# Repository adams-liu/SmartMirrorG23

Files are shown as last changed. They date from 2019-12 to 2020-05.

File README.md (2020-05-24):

# Smart Mirror Capstone Project :desktop_computer:

This project uses an amazon echo to communicate with the Raspberry Pi to create a hands-free media experience for the user.  We used [MagicMirror](https://github.com/MichMich/MagicMirror) repository as a reference for our work, they have a community to help you get started with your own magic mirror project. Click [here](Reports/G36-490_Final_Report.pdf) to see the full final report.
## Bill of Materials :dollar:
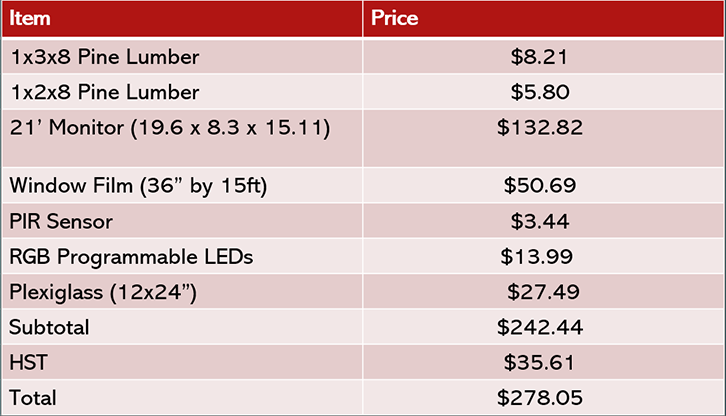
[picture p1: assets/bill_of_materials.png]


## Hardware Design :computer:
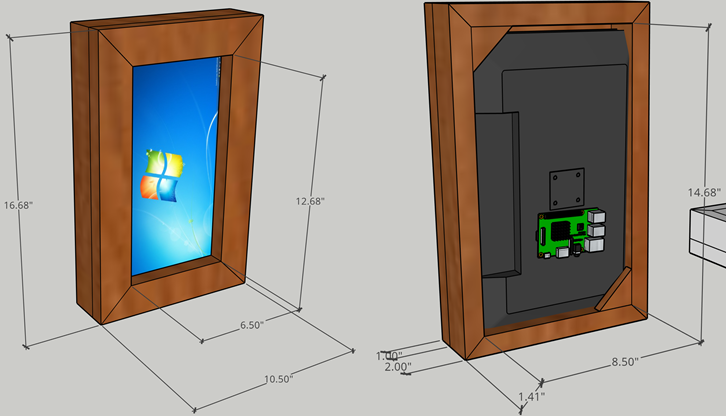
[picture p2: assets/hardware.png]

## Alexa Voice Integration :microphone:
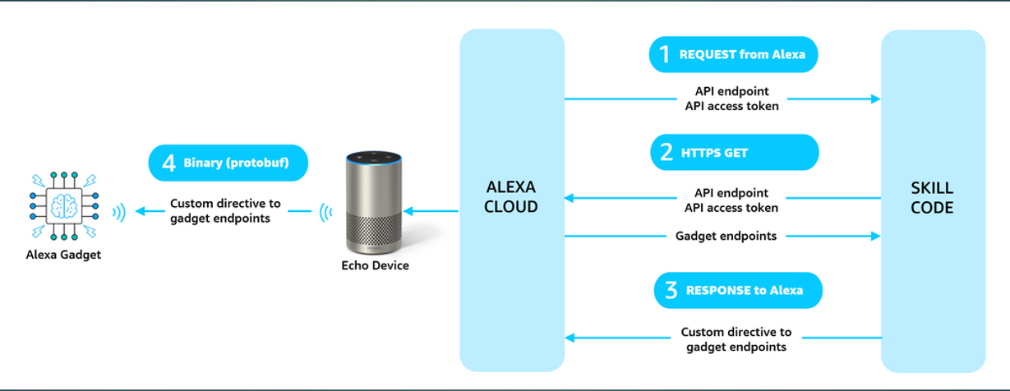
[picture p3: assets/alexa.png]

## User Interface :eyes:
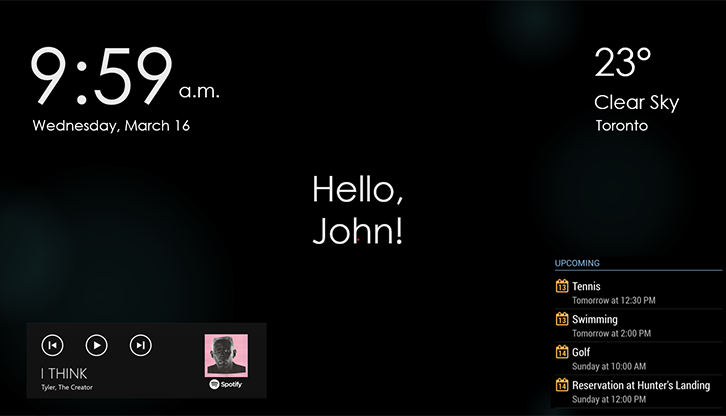
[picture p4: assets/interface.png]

## Starting the Mirror :running_man:
 > *This section is currently still being finished*

## Team :necktie:
- **Adams Liu** : Alexa Voice Integration
- **Ian Chang**: Hardware and Frame
- **Kingsley Chu**: User Interface

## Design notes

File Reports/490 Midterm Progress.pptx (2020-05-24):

## Smart Mirror

Midterm Progress
Group 36: Kingsley Chu, Adams Liu, Ian Chang
Date: dEC/05/2019

## Divided the roles into 3 parts

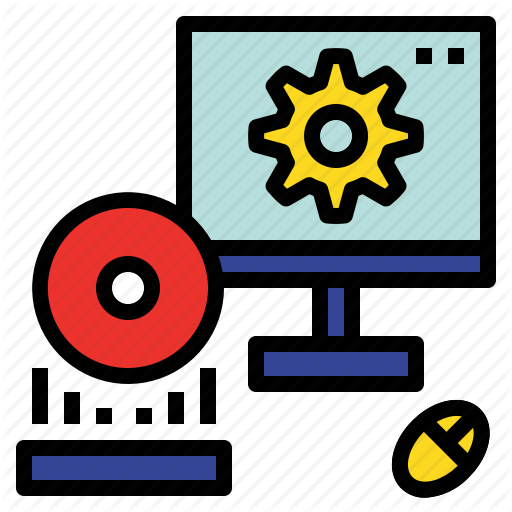
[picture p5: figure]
A close up of a logo Description generated with very high confidence

Hardware/Frame Development
[Ian Chang]

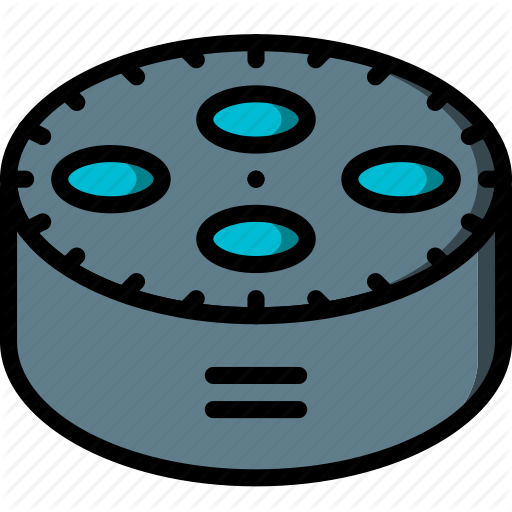
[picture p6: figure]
A close up of a device Description generated with high confidence

Amazon Voice Development
[Adams Liu]

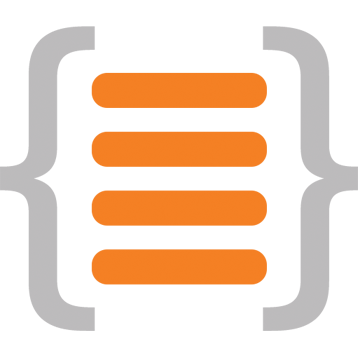
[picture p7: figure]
A picture containing flower Description generated with very high confidence

Fullstack + GUI Development
[Kingsley Chu]

## Hardware & Materials

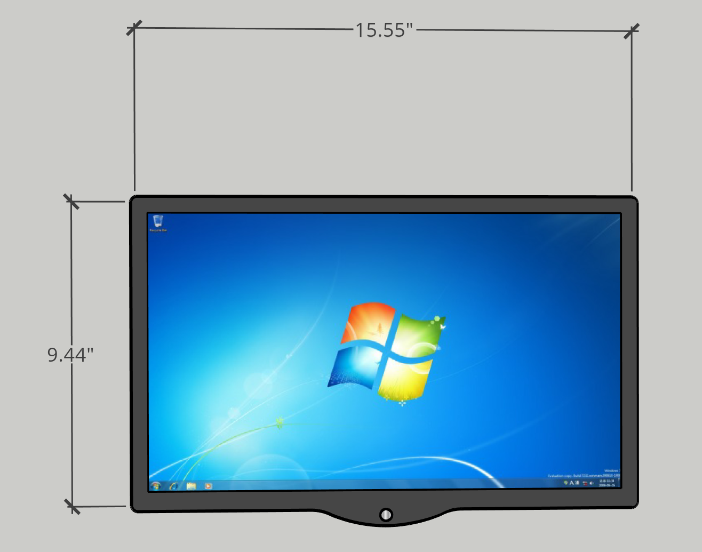
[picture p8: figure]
A flat screen tv sitting on top of a computer Description generated with very high confidence
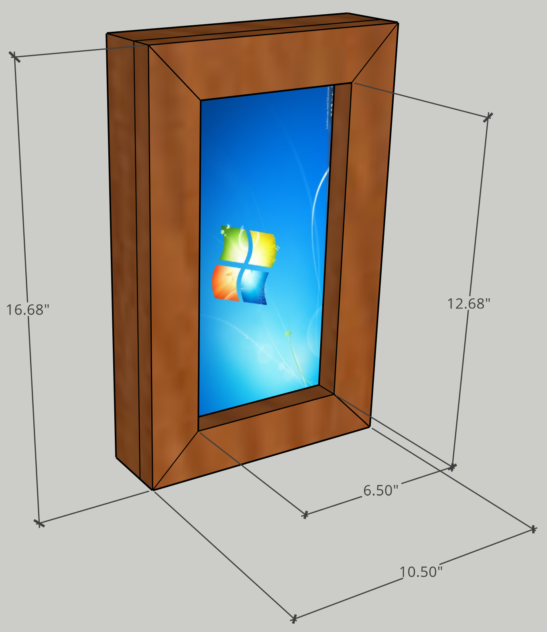
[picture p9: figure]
A picture containing computer Description generated with very high confidence
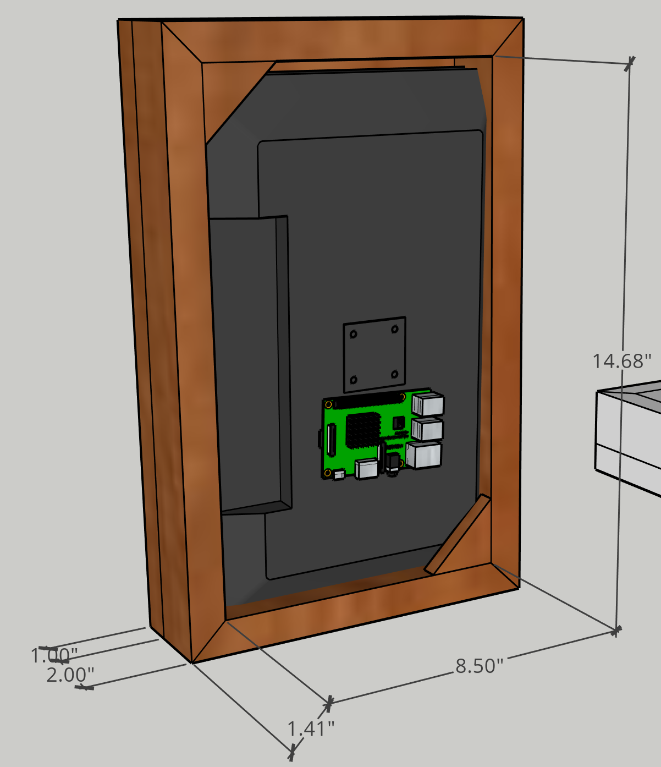
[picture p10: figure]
A picture containing table Description generated with very high confidence

## List of Materials

Item | Price
1x3x8 Pine Lumber | $8.21
1x2x8 Pine Lumber | $5.80
21’ Monitor (19.6 x 8.3 x 15.11) | $132.82
Window Film (36” by 15ft) | $50.69
PIR Sensor | $3.44
RGB Programmable LEDs | $13.99
Plexiglass (12x24”) | $27.49
Subtotal | $242.44
HST | $35.61
Total | $278.05

## Alexa voice integration

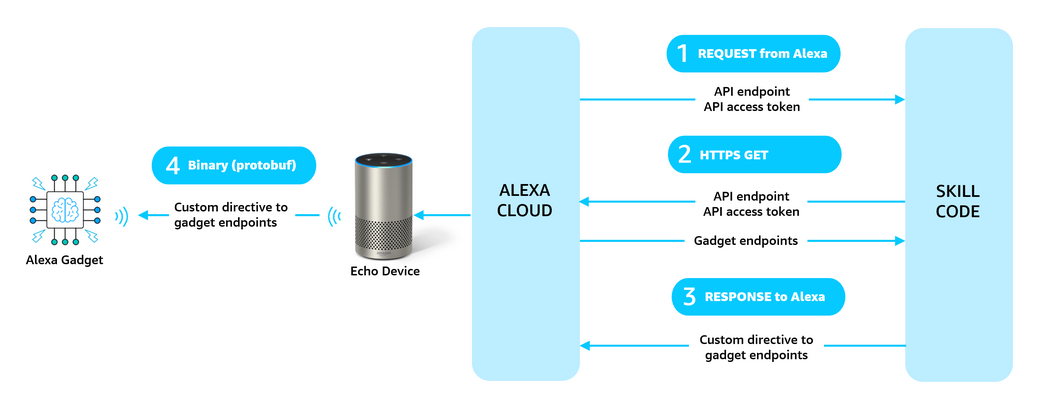
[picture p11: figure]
A screenshot of a cell phone Description generated with very high confidence

## Voice User Interface

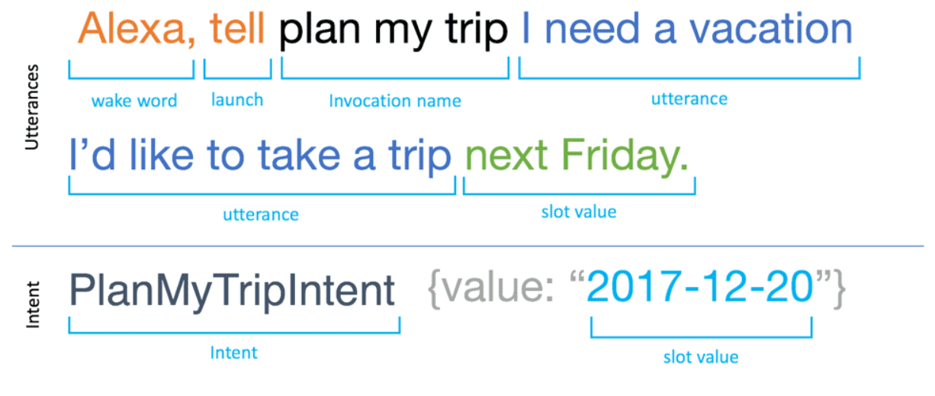
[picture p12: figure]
A screenshot of a cell phone Description generated with very high confidence

## Utterance and Intent (Schedule)

- Utterance:
  - "what's my schedule"?
  - "what does my schedule look like for today?"
  - "what's today's agenda?"
  - "what's today's to-do list?"
  - "what am I doing today?"

Intent 1: ReadScheduleIntent {value: 2019-12-05}
Call onto calendar API and return and responds by listing out schedule items for listed date

Intent 2: OpenCalendarIntent {value: 2019-12-05}
Communicates with Raspberry Pi to launch Calendar display for listed date

## Software & UI

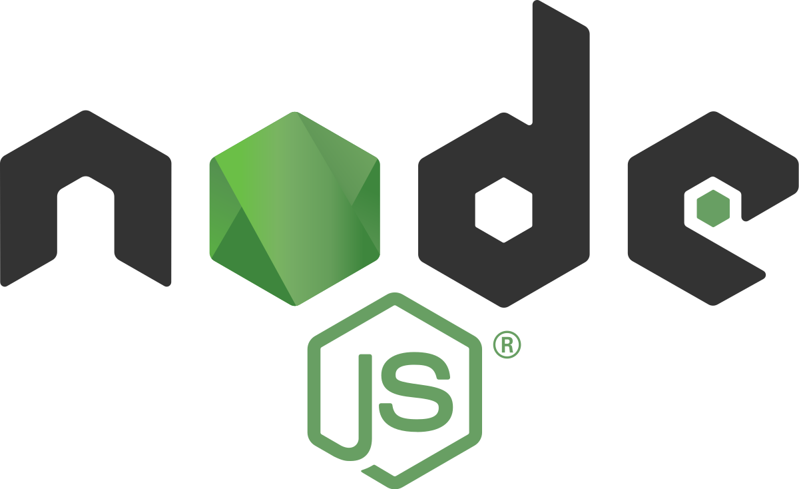
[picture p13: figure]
A close up of a sign Description generated with very high confidence
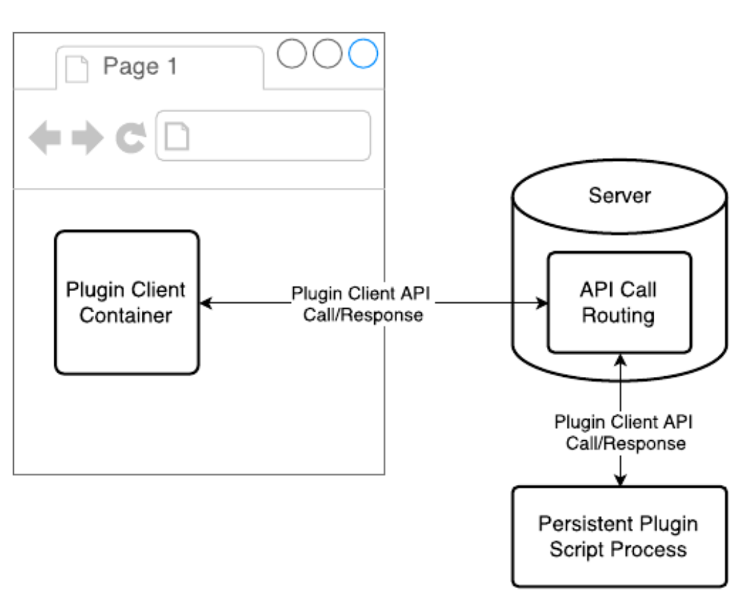
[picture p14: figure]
A picture containing screenshot Description generated with very high confidence
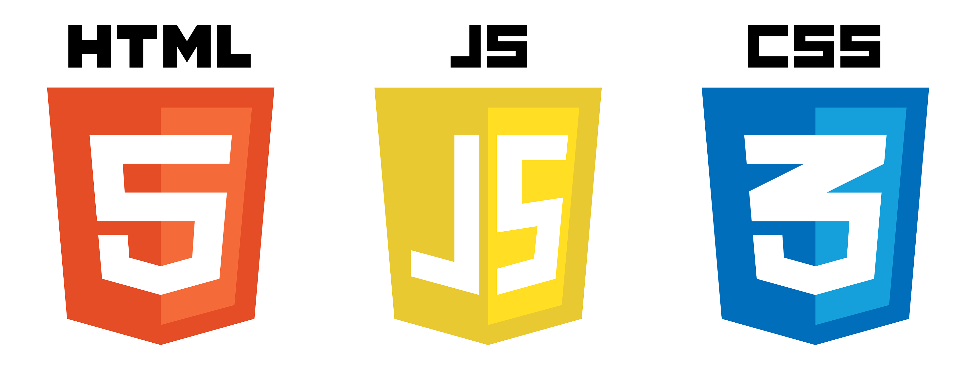
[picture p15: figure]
A close up of a sign Description generated with high confidence

## 9:59

Wednesday, March 16

23°

Clear Sky

Toronto

a.m.

Hello,
John!

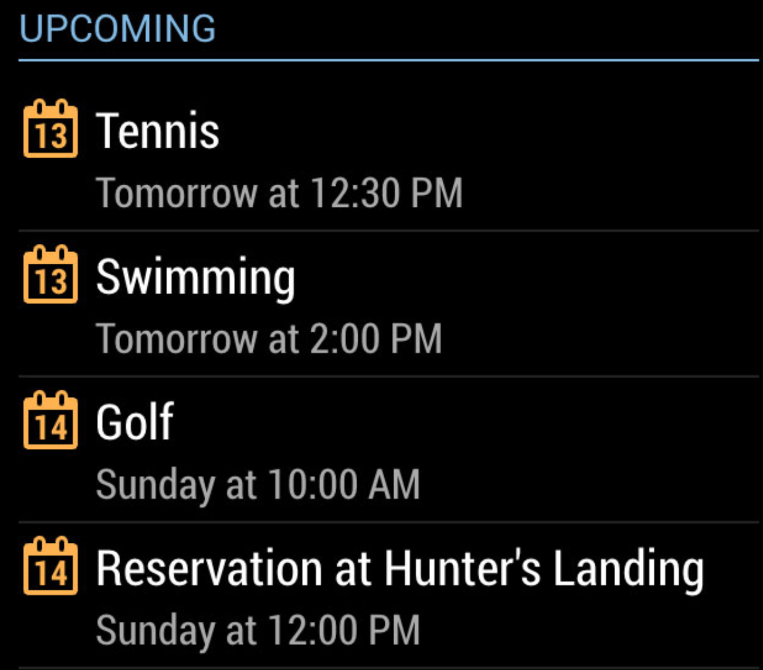
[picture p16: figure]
A screenshot of a cell phone Description generated with very high confidence
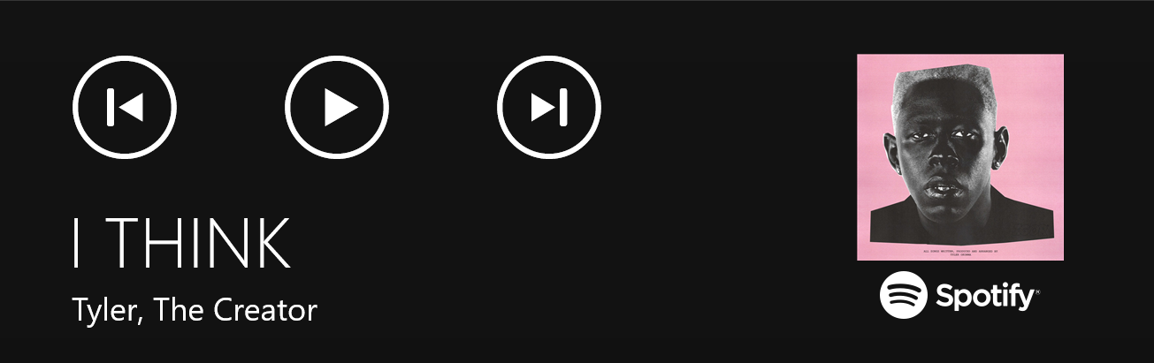
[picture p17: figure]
A picture containing shirt Description generated with very high confidence

## Next Steps

- Build the mirror
- Integration development between Alexa, Raspberry Pi, and Mirror
- Integration testing with between the ecosystem

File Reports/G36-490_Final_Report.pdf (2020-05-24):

# Queen’s University

# Assignment:

# Main Project Final Report

# Course:

# ELEC 490

# Group Number:

36

# Supervisor:

# Dr. Steven Blostein

# Prepared by:

# Adams Liu | #: 10187602 | 14zxl@queensu.ca

# Ian Chang | #: 10190262 | 14yc65@queensu.ca

# Kingsley Chu | #: 10182268| 14kmc@queensu.ca

# Due Date:

# April 5th, 2020

iv

## Table of Contents

## Table of Figures

Figure 5 A simplified workflow diagram displaying the relationship between the server and client

Figure 6 A code snippet of Node.JS utilizing an HTTP GET request to return a JSON containing

Figure 7 Diagram flowchart to illustrate the OAuth 2.0 authentication process to request a song through

Figure 8 A code snippet of an RNG (random number generator) that is used to poll a preset array of

Figure 9 Sample JavaScript code that runs index.html as an Electron app with a dedicated window instead

Figure 10 Data Flow diagram of the Amazon Alexa Voice Skill Kit software, showing the request and

Figure 11 Natural Language Processor breakdown with various functions. Note the natural language

## Table of Tables

## Executive Summary

As the world we live in continuously evolves and modernizes with new technologies, humans as

well aim to optimize and improve their schedules and resources. However, the most important resource that

no money can buy is time, and by identifying key chokepoints of data integration and acquisition in one’s

daily schedule, this project aims to streamline the deliverance of important information to the end-user.

With the use of a Magic Mirror, this futuristic project integrates modern user-centric design with cutting

edge technology focused on delivering the most informative washroom experience yet, through the

application of various engineering feats, such as building a fully functional and ergonomic user interface

with beneficial functions that symbiotically blends with the physical world environment, as well as a natural

language processing module for user input. By integrating human-centric design with the agile software

development process, this Magic Mirror leverages existing technologies such as Amazon Echo, Raspberry

Pi, Electron, and Web development to bring the future to you.

## Motivations and background

The term Internet of Things (IoT) describes “technologies, systems, and design principles associated

with the emerging wave of Internet-connected things that are based on the physical environment” [1]. IoT

is further explained as a network of uniquely identifiable objects, things, and their virtual representations

in an internet-like structure [2]. To be simply put, the IoT concept is exemplified when an object has the

ability to transfer data over a network without the need for human to computer interaction. IoT comprises

four components, including sensing, heterogeneous access, information processing, and applications and

services [2].

With the advancement of technology, people want to access information more easily. Whether it is

through the television or the internet, people want to be informed of the news and the world’s current affairs.

Along with the growth of smartphone users, consumer adoption of IoT devices has over greatly increased

over the past few years. According to the International Data Company (IDC), worldwide spending on the

Internet of Things was forecast to surpass the $1 trillion mark in 2022, a double-digit annual growth rate

throughout the 2017-2022 period [3]. Industries, governments, and consumers are quickly adopting IoT

into daily life. Current well-developed commercial products such as smart door locks, smart plugs, and

smart thermostats have been changing the way consumers are informed on the status of households,

vehicles, family members, and even their own health.

Among the smart home products that have been developed, the mirror remains in a relatively

primitive state. In 2006, a research paper on “information-accessing furniture” was published in Tokyo,

Japan, detailing one of the early prototypes of a smart mirror, called the “Miragraphy” [4]. The system was

able to display news headlines and personal picture galleries [4]. A “smart rear-view mirror” was developed

in 2014 by Nissan, which consisted of a mirror with a built-in LCD screen that displayed high-resolution

videos of the car’s rear flanks [5]. While research has been done in the past on a smart mirror system, the adoption of smart mirrors has been low due to the high cost of production, insufficient functionality, and

lack of integration between the smart mirror and other smart home devices [6].

To deal with the situation, the Smart Mirror system was developed to provide users with the

convenience of accessing relevant information in addition to managing their smart home devices. The Smart

Mirror enables the users to provide oral instructions, and the system will recognize the user’s voice to

receive instructions and respond to the users’ needs. Moreover, the Smart Mirror system will be

implemented on a low-cost system on chip (SOC) devices such as the Raspberry Pi.

The smart mirror system will be developed based on three objectives shown below, as major

components key to functionality:

1. Use the Raspberry PI as a component in the hardware design.
2. Incorporate a voice control system that enables smart mirror navigation.
3. Enable the mirror to be user-customizable

## System Design

From the beginning, we understood our project had a heavy emphasis on integration, which requires all

components of our system to be working simultaneously and working with each other. These subsystems

included the hardware system, the user display system, and the voice-controlled system. If one subsystem

were to fail, then the entire smart mirror system would not be able to operate. For example, if the PIR sensor

did not work, then the monitor would not be able to turn on, which meant that the user display and voice

control subsystems would also be unusable. Our team understood that building the smart mirror system would

have to be a sequential approach, and priority needed to be focused on what is most crucial to the operation

at the time. For example, it would be unwise to start programming the RGB LEDs before getting the voice-

controlled system operating first, as the primary purpose of the mirror is to give users a voice-controlled

display. This made decision making very easy as everyone in the team agreed on what needed to be focused

on. Figure 1 is a diagram that displays a flow chart of tasks and in what order they should be done in

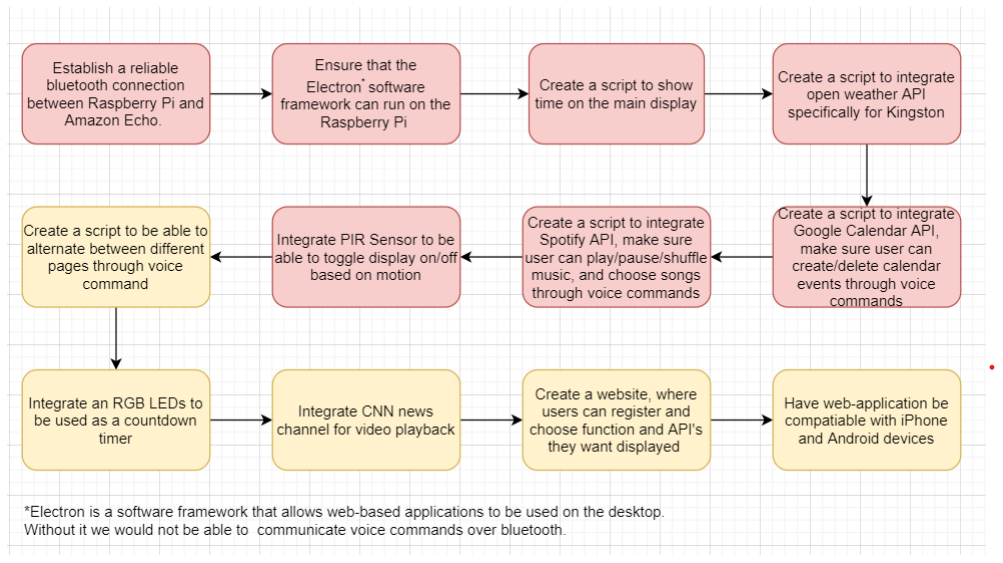
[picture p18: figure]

Figure 1 Flow-chart of Tasks

The red boxes highlight the requirements that our team wanted to accomplish by the end of the

year, and the yellow boxes indicate stretch goals that our team would like to accomplish if time allowed.

Thankfully, we were able to meet expectations and complete all crucial tasks (red) as well as accomplishing

the first stretch goal (yellow).

### Functional Requirements

The functional requirements of our project are structured based according to the design process as

well. Table 1 shows the functions of our system as well as an example of voice commands (if required) that

the mirror system can perform to trigger those functions.

Table 1 Functional Requirements with Example Voice Commands

Functional Requirement | Example of Voice Command
The mirror will be able to toggle on/off through voice command. | • “Alexa, turn on the mirror” • “Alexa, turn off the mirror”

The mirror will be able to accurately display the current time (Eastern Standard Time)

The mirror will be able to connect to OpenWeatherMap API service and display daily weather for Kingston, Ontario.

The mirror will be able to connect to Google Calendar’s API service, and users will be able to add/delete/update calendar events that will display dynamically on the mirror | • “Alexa, add Event for 3 O’clock this afternoon to go pick up Sally from daycare • “Alexa, delete meeting with Kevin today” • “Alexa, update meeting with Jillian, from 7 O’clock to 7:30”
The mirror will be able to connect to Spotify’s API service, and users are able to pause/play/shuffle/choose songs through voice command. The display should be able to match said command. | • “Alexa, play music” • “Alexa, stop the music” • “Alexa, play songs by Justin Bieber”

The mirror’s display will be activated only if the PIR sensor detects movement within 3m of its peripheral

When no movement is detected for 30 seconds the mirror’s display will turn off

The mirror will be able to navigate to different user pages through voice command and a given name | • “Alexa, go to Mark’s page”

### Constraints

Due to time constraints, we were unable to implement a customizable display where users can

choose which Nodes and APIs that they would like to be displayed. Currently, the functions are pre-set in

the backend, and unless users have intermediate node.js knowledge, it is very cumbersome to change the

display. In the future, we hope to create a drag-and-drop web application that allows users to customize

their display tailored to their needs.

Another constraint our product has is the limited account constraint. Currently, the system only

allows one Google account, and one Spotify account to be connected. This is not ideal, considering we

intend the mirror to support multiple users. Having a database of users for the mirror system will be

implemented in future iterations.

The final major constraint is the language constraint. Currently, the voice-controlled system only

supports American English. Therefore, the mirror would not be suitable for anyone who is not is an English

speaker. It also does a poor job with accents as well. Later iterations of the mirror will include more

languages to support international users.

## Solution Implementation

### Software Specifications and Implementation

As a bulk of the project was implemented through software development, various development

tools and technologies were used to accomplish the project task. This includes utilizing web development

technologies integrated with the internet of things (IoT) devices. To create the software application to

achieve the project task, several key packages were utilized based on simplicity, effectiveness, and overall

usability. This can be illustrated in figure 2 below

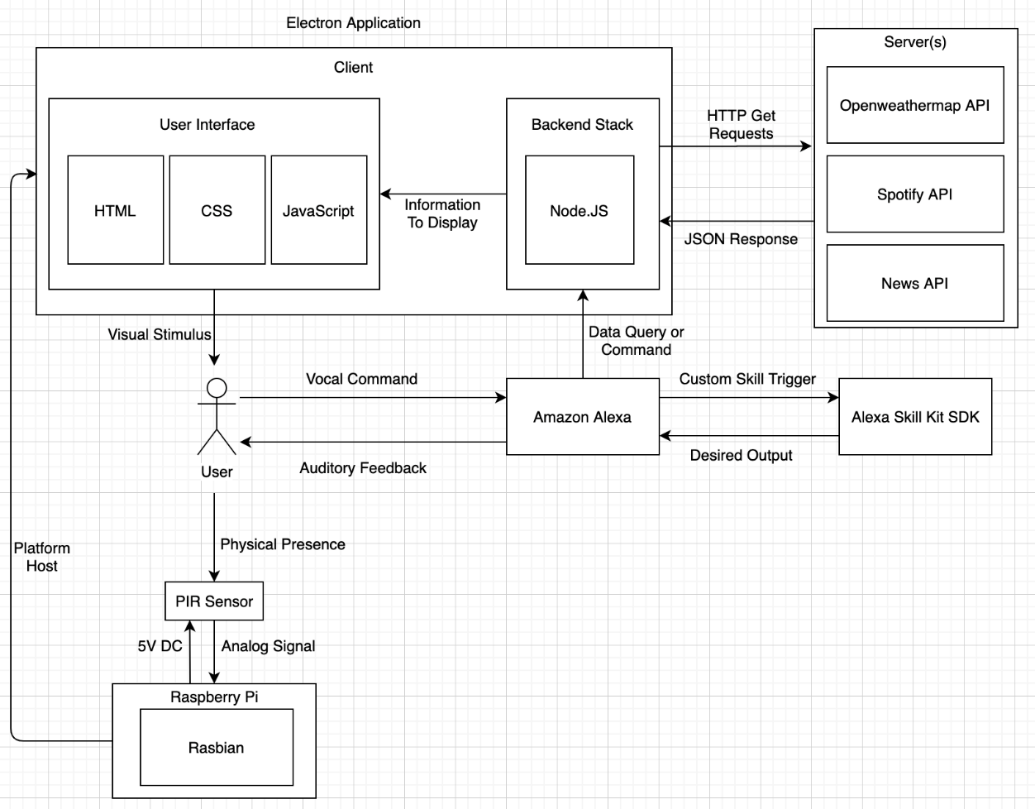
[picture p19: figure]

Figure 2 Level 1 data flow diagram of the magic mirror software

In addition, the use case diagram for the software system is shown below in figure 3. This outlines

the possible ways for an actor or user to interact with the Magic Mirror system:

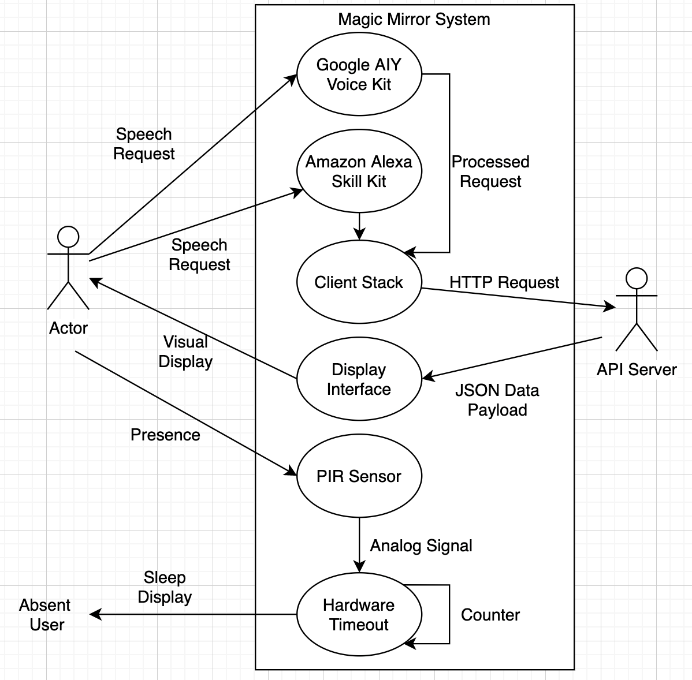
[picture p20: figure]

Figure 3 A use case diagram for the software of the Magic Mirror

Moreover, as the main application of the project is a visual interface designed to effectively relay

information to the user, a web-based program running on Electron was chosen. This entails a front-end

stack comprised of HTML, CSS, and JavaScript to build the user interface, selected for stability,

maintainability, and simplicity. In addition, and monochromatic color scheme with a black background

would allow white text to stand out through the one-way mirror clearly while avoiding interference with

the reflection An original prototype static mockup, used as a low fidelity (Lo-Fi) prototype is shown in

figure 4:

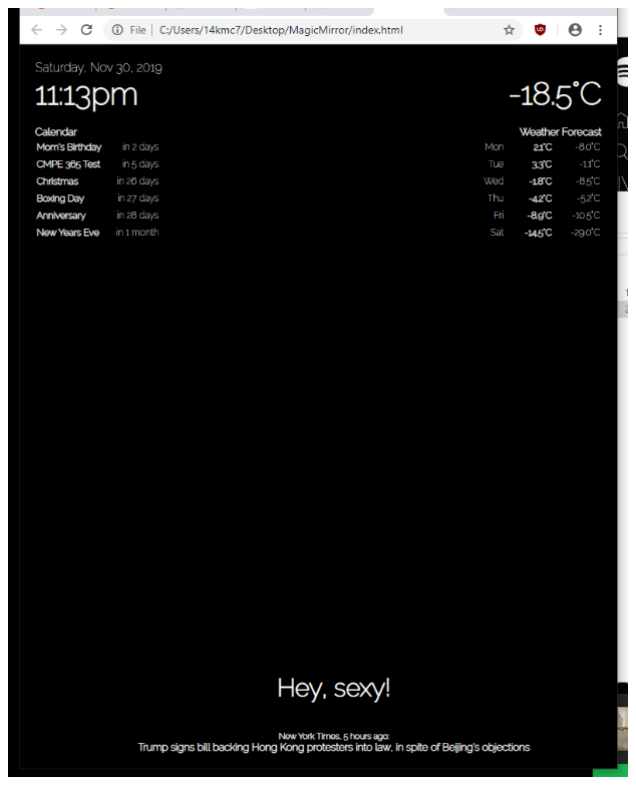
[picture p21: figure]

Figure 4 The orignal Lo-Fi static mockup of the user interface

Later, a high fidelity (Hi-Fi) front-end stack would utilize basic HTML to display text and icons,

which are key to creating a clear and basic interface that would be relayed through the IPS display and one-

way mirror. Such items would be conveyed using dedicated widgets for specific functions, which are listed

below:

- Time and date, which utilizes built-in JavaScript functionality such as getDate() with options for

formatting such as ISO8601, to display the current time and date as the main widget. This is stylized

by CSS, which affects the visual aesthetic of the date.

- Weather widget, which is dedicated to displaying weather data alongside the current time and date.

This weather widget utilizes a dedicated representative state transfer application programming

interface (REST API), specifically the openweathermap.com weather API, as shown in figure 5.

This utilizes a Node.js framework backend, which allows the front-end to produce usable

functionality. This JavaScript library is built to allow the transference of weather data through a

JavaScript Object Notation (JSON) file, which returns desired weather data such as temperature,

condition, high, low, and upcoming forecast for the weather as a response to a Hypertext Transfer

Protocol (HTTP). This HTTP request (in the form of GET), will request information based on the

location, amount of data needed, and format of data in metric or imperial units. The response is

parsed, and data is conveyed into a dedicated weather class object, with fields such pertaining to

relevant information. In addition, the API will return location data along with the weather data,

which can be useful in display in the time zone and location. This data is also parsed through the

HTML, CSS front end stack, and stylized in a clean aesthetic for display. An example is provided

in figure 6 below

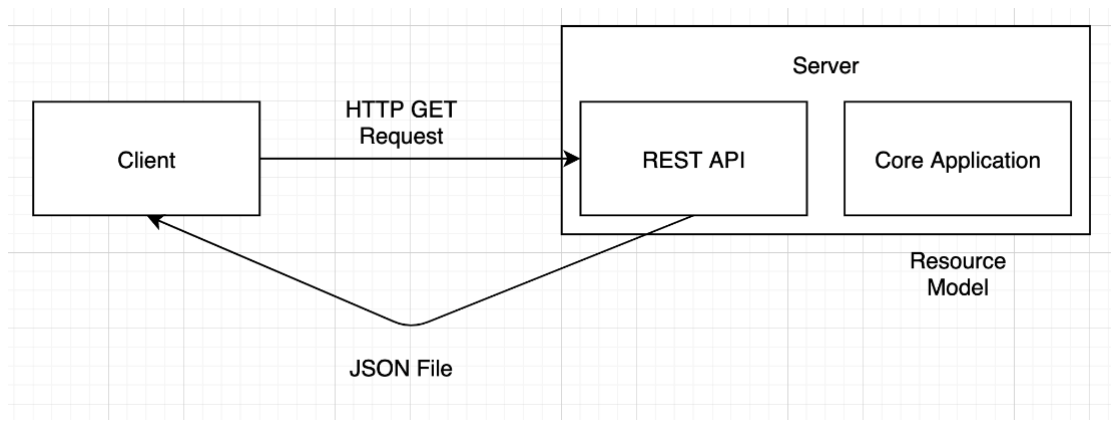
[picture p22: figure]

Figure 5 A simplified workflow diagram displaying the relationship between the server and client executing an API GET request

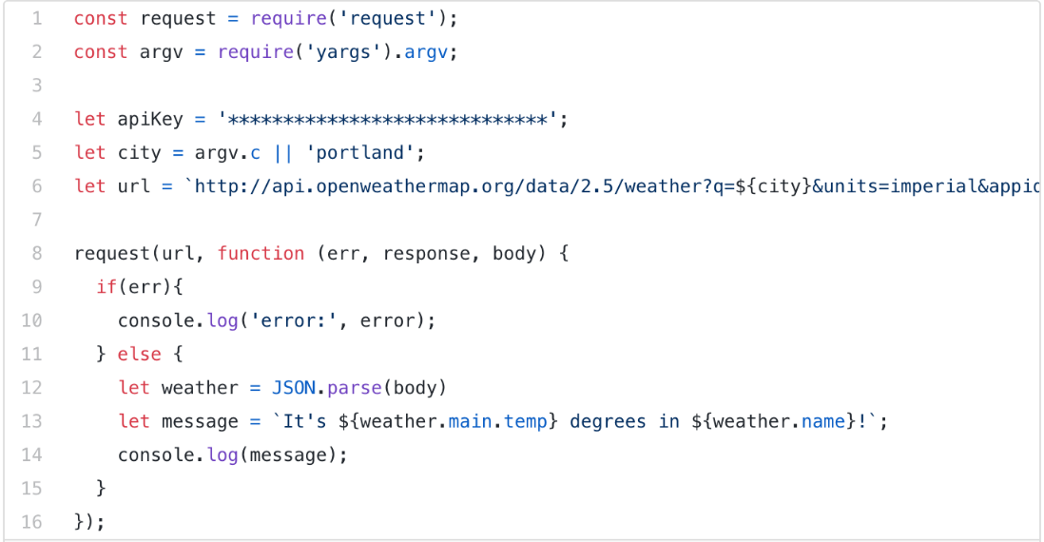
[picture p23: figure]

Figure 6 A code snippet of Node.JS utilizing an HTTP GET request to return a JSON containing requested weather data

- Spotify widget, which utilizes a proprietary API through a preregistered Spotify account, which

will allow for music to be played back through the connected Amazon speaker. This Spotify widget

displays the current track name, artist, as well as album art to allow the user to visually perceive

the song. With similar functionality to the weather widget, the Spotify widget will require a similar

protocol when updating and requesting information from the API through the internet, with the

added addition of authentication, as shown in figure 7. Due to the monetization, legalities, and costs

associated with listening to music, Spotify’s paid account requires the user to be verified through

OAuth2.0, which is a special authentication protocol and open standard required for access

delegation, used for internet users to grant websites or applications access to information. Users

will not need to deal with the OAuth authentication, as the Node.js backend code will accept the

user’s credentials during setup and resolve authentication for Spotify use.

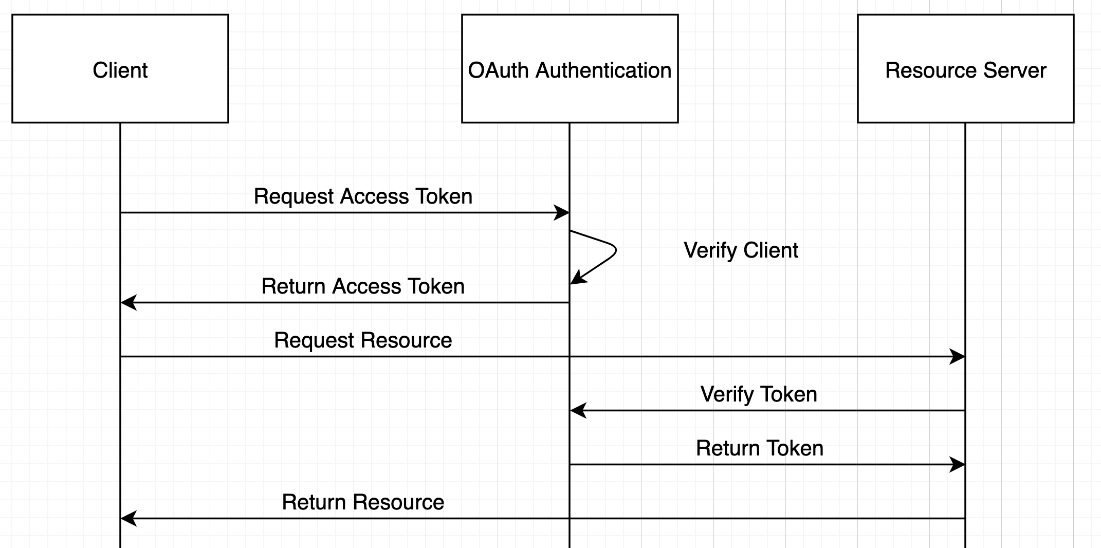
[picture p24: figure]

Figure 7 Diagram flowchart to illustrate the OAuth 2.0 authentication process to request a song through the Spotify API

- Another feature or widget is the quote of the day, which, unlike the other widgets, does not utilize

a specific API through internet connectivity, but instead polls from a randomly generated list of

quotes. These will include encouraging or entertaining phrases, which is displayed to the user

through the front-end stack. By utilizing a random integer generator function in JavaScript,

random(), a randomized index retrieves a specific phrase from an array or dictionary of strings,

which is parsed, displayed, and stylized with HTML and CSS as shown in figure 8. Such phrases

include “You miss 100% of the shots you don’t take – Wayne Gretzky” and “Hey, sexy!”. This

poll will update once per day, and the widget will adjust accordingly. However, it was decided in

the final iteration to omit this feature.

Figure 8 A code snippet of an RNG (random number generator) that is used to poll a preset array of quotes

- A news headlines aggregate that displays headlines like the weather data, which polls from a

specific API such as News API through the form of an HTTP get request, with a JSON response.

This allows for only the news headline to be shown through the front-end stack, which is refreshed

every minute.

Finally, addressing the hardware platform that the application is run upon, a cross-platform desktop

program would be ideal, as it can allow developers to improve and design upon multiple iterations during

the prototype testing on personal computers while taking full advantage of the Raspberry Pi’s portable

system. This requires a cross-platform, simple, and light framework that can utilize existing web

technologies, which Electron is suited for. This reduces the need to run the program through a web browser,

such as Firefox or Chrome. A sample code snippet of wrapping an index.html file through an Electron

application is shown below in figure 9:

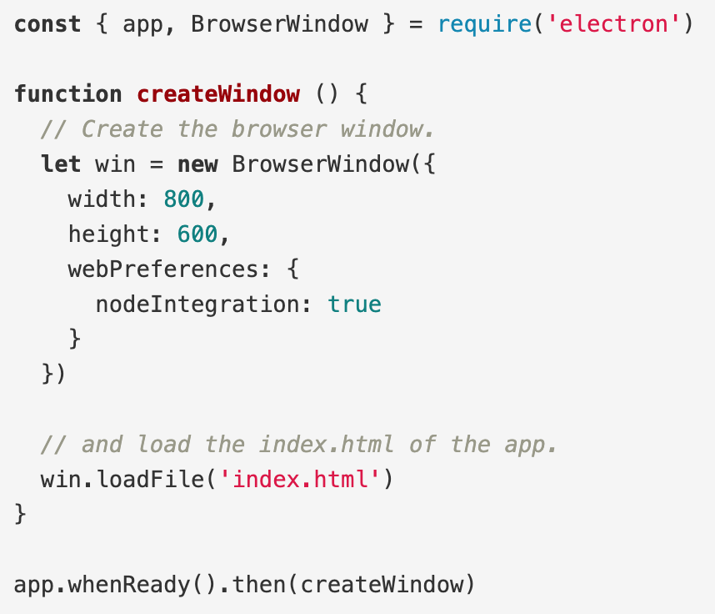
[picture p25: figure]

Figure 9 Sample JavaScript code that runs index.html as an Electron app with a dedicated window instead of a webpage

Finally, the decision to integrate an Amazon Echo module with the Magic Mirror application is due

to the design of the Mirror and the limitations in interactions a user may have using this particular interface.

As the user will not be able to interface with the application through haptic or physical interaction, the use of a natural language processor to receive input commands is extremely effective in solving the issue of

input from the user. This will require integration of the Amazon Alexa Skills Kit. This kit is used in

conjunction with the main application to process the user’s vocal inputs, which is designed to flow data to

the voice processor, which includes speech recognition, machine learning, natural language processing with

linguistics, and text to speech for reply. This sends a request to a custom Alexa voice service set up by the

developers, which returns a JSON response of the appropriate response. However, the Alexa voice service

is configured and trained to receive certain custom commands, such as paging to a specific widget or

updating that specific widget, which is extremely useful for specialized applications such as this project.

This data flow can be seen in figure 10 and figure 11 below:

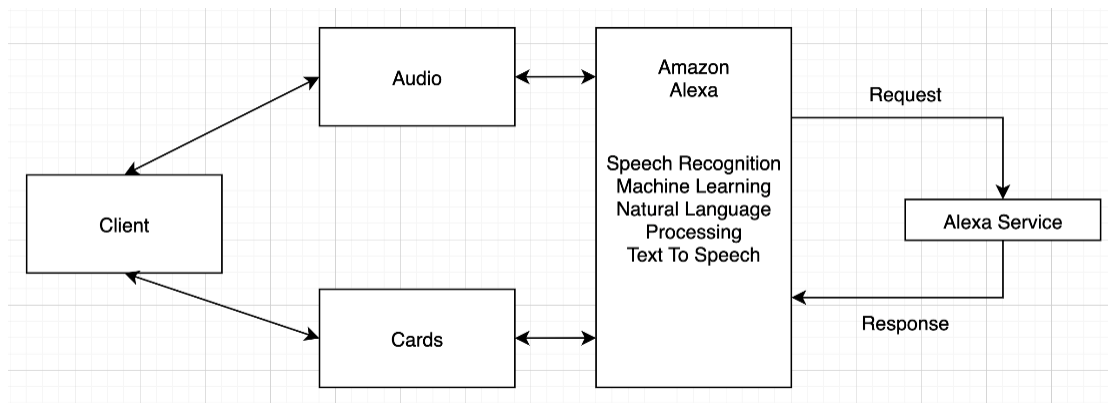
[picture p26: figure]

Figure 10 Data Flow diagram of the Amazon Alexa Voice Skill Kit software, showing the request and response of an Alexa Voice JSON

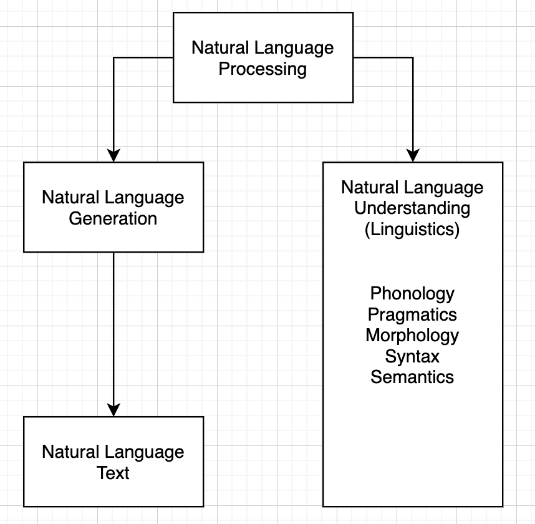
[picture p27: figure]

Figure 11 Natural Language Processor breakdown with various functions. Note the natural language generation module that recites certain text for auditory user feedback

### Hardware Implementation

The main components for hardware implementation involved in creating the smart mirror system

include a computer monitor, a Raspberry PI, a wooden frame, and a reflective window film. With those

components, the developed smart mirror would be able to perform its most basic functionalities. To further

expand on the basic components, additional components were used, such as the PIR sensor, Amazon Echo

Dot, and the RGB LEDs. The full bill of materials for the project can be seen in table 2 below.

Table 2 Bill of Materials for the Project

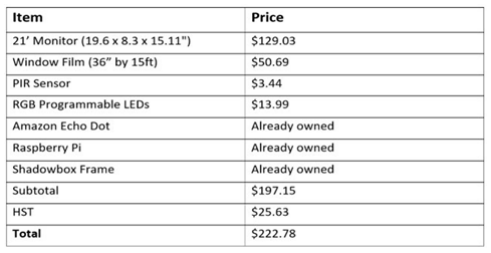
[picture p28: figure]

As seen in the table, the main spending for the project was the 21’ monitor, reflective window film,

the PIR sensor, and the RGB LEDs. The other components, such as the Raspberry Pi, the wooden frame,

and the Echo Dot, were already owned by the group members. The final amount was $222.78 spent out of

the total $400 budget that was given to the group.

The main initial steps for hardware development involved in assembling the frame for the smart

mirror. For the frame of the mirror to be set up, the computer monitor must be placed within a wooden

frame with the front opening of the frame covered with a piece of glass. The back of the wood frame would

also include an opening allowing the installation of the Raspberry PI unit and creating space for the power

supply wires to exit the frame. The general CAD designs for the wooden frame was created in Google

Sketchup and can be seen in figure 12 and figure 13 below. The designs seen below is labeled with general

dimensions of the wooden frame and the monitor used. Figure 12 shows the front view of the frame showing

the wooden frame opening where a glass panel would be added to allow monitor display to show. A

reflective film would be added on top of the glass panel to create a one-way mirror effect, making the

surface of the glass reflective while still displaying the contents of the monitor. Figure 13 below shows the

back view of the mirror, where a Raspberry PI unit can be seen attached to the back of the monitor. In

addition, two wooden pieces can be seen; one in the top left corner, and the other in the bottom right corner

of the monitor, which are used to secure the monitor into the wooden frame.

While conventional methods required for the wooden frame to be custom made to fit the

dimensions of the computer monitor, a group member was able to obtain a premade 20’ by 20’ shadowbox

frame that fits the dimensions of the 21’ monitor purchased, allowing the group to skip the process of

creating custom fame and the wooden pieces to needed to secure the monitor. The shadowbox frame that

was used for came with a clear plastic panel which also substituted the glass panel needed in the original

design of the frame. To complete the assembly of the mirror, the group placed the computer monitor within

the frame and applied the reflective film on top of the plastic panel. In the back of the frame, openings were

left for the power supply cables of the monitor and the Raspberry PI unit to exit.


Figure 12 The front view of the frame


Figure 13 The back view of the frame

One of the drawbacks of using the prebuilt shadowbox frame was that the monitor’s display did

not take up the entirety of the frame’s openings. Although the monitor did indeed fit into the frame securely,

approximately half of the wooden frame’s opening is left uncovered by the monitor. Therefore, to prevent outside light from entering the frame from the back of the frame, a black cardboard cutout was used to

cover the residual space in the back of the frame. The black background within the wooden frame enhanced

the reflectivity of the mirror surface.

On the back of the monitor, the Raspberry PI unit was attached, connecting the monitor’s HDMI

input and the PIR sensor’s signal input. Figure 14 below shows the wiring of the PIR sensor on the

Raspberry Pi. As seen in the figure, wires were connected to the 3.3V power supply, ground, and signal

input on the Pi’s unit. The PIR sensor exits from the back of the frame and is placed on the top surface of

the frame, facing the front. This placement of the PIR sensor is to enable the sensor to detect movement in

front of the smart mirror and trigger the turn off signal if no movement is detected.

The Amazon Echo Dot was used in the hardware setup of the smart mirror to enable a microphone

input into the smart mirror system. The Echo Dot is built-in with an Amazon Alexa voice assistant which

was used to enable voice commands for the smart mirror interface. The hardware setup for the Echo Dot

unit was separate from the wooden frame and only a required wired connection to a nearby power outlet.

The Amazon Echo Dot would communicate with the Raspberry PI unit through a private Wi-Fi network.

The RGB LEDs were purchased by the group with plans to attach the LEDs on the perimeter of the

wooden frame to enable a lighting effect when the user used different features of the smart mirror system,

such as a countdown timer. However, due to time constraints in the development of the interactive software

modules for the smart mirror, the group decided not to implement the LEDs as part of the hardware design

of the smart mirror.


Figure 14 Wiring of the PIR sensor to the Raspberry PI

## Testing, Evaluation, Verification, and Validation

The main methods of testing used in the project were technical input testing and user testing. Once

the base features of the smart mirror were developed, the technical input testing was performed on the

system. To conduct the technical testing of the smart mirror, each functional requirement decided by the

group was set up as individual test cases, as seen in table 3 below, where various user inputs were used to

test the system outputs. The objective of the test case is then compared with the actual system results, where

changes were made to the system if the test case fails.

Table 3 List of Test Cases for Technical Testing

Test Case | Objective | Test Results
Toggle Mirror on/off with voice command. | The mirror turns on/off when the user says voice command, “Alexa, turn on the mirror” or “Alexa, turn off the mirror.” | Success. The mirror was able to turn on and off correctly, whenever the user issues voice correct voice command.
The time module displays the current time. | The time module accurately displays time in a set time zone. | Success. After the configuration of a specific region, the module

| | accurately displays the time for the specified region.
Weather Module displays current weather. | The weather module connects to the OpenWeatherMap API and displays the correct weather for the configured location. | Success. The weather module was able to accurately display the weather of the configured location.
The calendar module displays user scheduled events. | Calendar module connects to the Google Calendar API, allows users to add/delete/update calendar events, and dynamically updates calendar events. | Success. The calendar module was able to connect to the Google Calendar API and dynamically change and display user’s calendar events.
Spotify Module plays user-specified music. | The module is able to connect to Spotify API and enable users to pause/play/shuffle/select music on command. The module displays the music that is currently playing. | Success. Spotify module was able to connect to the Spotify API and correctly play the user-specified music and change on user command. The module accurately displays player for music played.
PIR sensor toggles mirror display after detecting movement. | PIR will toggle the monitor’s display on/off if the sensor detects movement within 3m of its range. | Failure. During initial testing, the PIR sensor did toggle the monitor on and off accurately when the user stood in front of the mirror.

Mirror user interface switches to

different user pages.

When a user uses voice

command “Alexa, switch to

____’s page,” the mirror UI will

navigate to the user’s page.

Success. Mirror was able to

switch to the correct user page

when after the user’s specified

voice command.

As seen in table 3 above, during initial testing, most of the technical test cases were successful in

achieving the test case objective. The PIR sensor during initial testing did not consistently toggle the mirror

on or off when it detected user movement. When the user stood within the sensor range, the PIR sensor

would sometimes toggle randomly and turn off the mirror display. In other trial runs of the PIR testing, the

PIR sensor would seem to turn itself on when there is nothing within the sensor range. After multiple test

runs of the PIR sensor, it was found that there was a 30-second delay set on the PIR sensor settings. After

reducing the sensor delay to less than 30 seconds, the PIR reacted to the user movement more accurately,

with the screen toggle going off shortly after sensor detection.

For the method of user testing for the smart mirror, a survey with specific and open-ended questions

was sent to people to help understand their familiarity of the smart mirror system and to gain insight on

their interests of the system. The process of user testing helps the group validate whether there is a need for

a smart mirror system and if there are modules that users would like to see added onto the system. The

survey was given to eight people within the age group of 18-60, with the majority of people in the age group

of 18-24. The people surveyed were asked to try to answer the question in the survey to the best of their

abilities. The survey questions and answer summaries can be seen in the appendix below.

Analyzing the survey results reveal that there is great interest in a smart mirror system in a

household setting. Survey results show that 62.5% of people use at least 2 mirrors personally, and 50% of

people spend 1-5 minutes in front of the mirror in the morning. When asked what the most stressful

activities in the morning are, 62.5% of people answered along the lines of commuting and catching the bus.

When asked what features the users would like to see in a smart mirror, 25% answered a module on bus schedules or weather. When asked if users would be comfortable with an infrared sensor in front of the

mirror to sense for user movement, all users answered that they are comfortable. When asked how likely

they would want a smart mirror in their home, given a scale from 1-5, with 1 being very unlikely and 5

being very likely, the majority of people answered above a 3 and with 50% of people answering a 5 for

very likely.

### Related Work

The group surveyed other related work on related to interactive mirrors and the smart mirror system.

In 2006, researchers in Tokyo, Japan, published a paper on “information-accessing furniture,” one of which

was an interactive user mirror called the “Miragraphy” [4]. The system design was a mirror that had an

embedded module behind it containing a small computer and projector that superimposed the projected

image through a diffusion film outward [4]. The Miragraphy was able to display weather and news

headlines in its display. In October 2016, a project similar to the group’s smart mirror system was created

in Edmonton Alberta under the name “Smart Reflect” [7]. The Smart Reflect system also uses a similar

design to our group with the use of a Raspberry PI as the core of the system and a mirror with an embedded

monitor as its source of display [7]. The user interface was a lightweight process and but lacked in user

customizability and voice control [7]. In November 2016, a smart mirror project was created at Ulm

University, Germany, called the “FitMirror” [8]. The FitMirror system created with a display behind a

mirror frame, in addition to adding components such as the Wii Balance board and the Microsoft Kinect

[8]. The main purpose of the FitMirror was not for entertainment but for tracking the user’s health [8].

In comparison to the other related research on the smart mirrors, the group’s smart mirror system

was found to be simpler, more lightweight, and user-customizable. As tested to be compatible with the

Raspberry PI, the smart mirror system demonstrated that it is computationally lightweight. The group’s

smart mirror system integrates voice control through the use of the Amazon Echo Dot, enabling the users

to control the smart mirror hands-free. Moreover, the group’s smart mirror system is set apart from the other existing work through the ability for multiple users to customize their own display and further extend

module functionality.

## Stakeholder Needs

As this project was able to simulate the full lifecycle of the engineering product development,

various stakeholders are required to be considered for each stage for the project to meet and exceed all

requirements. This will involve several stages and considerations from the initial planning stages outlined

in ELEC 390 Electrical and Computer Engineering Design, where the engineering and development cycles

were initiated. Several stakeholders typical of a life cycle stage would include acquirer, panel or potential

users, marketing division, research, and development department, standardization body, supplier,

verification and validation team, production system, certification or regulatory authorities, design

engineers, and integration team as outlined in table 4 below:

Table 4 Stakeholder indentification based on life cycle stage

Life Cycle Stage | Example of Related Stakeholders
Engineering | Acquirer, a panel of potential users, marketing division, research, and development department, standardization body, suppliers, verification and validation team, production system, regulator/certification authorities, etc.
Development | Acquirer, suppliers (technical domains for components realization), design engineers, integration team, etc.
Transfer for Production or for Use | Quality control, production system, operators, etc.
Logistics and Maintenance | Supply chain, support services, trainers, etc.
Operation | Normal users, unexpected users, etc.

Disposal | Operators, certifying bodies, etc.

However, the later life cycle stages, such as logistics and maintenance, operations, and disposal,

are less applicable, and a greater stakeholder weight is placed on the engineering and development life cycle

phases. This will include the consideration of the Faculty of Engineering as the validation and verification

team, supplier, and development department, the engineering design and integration teams, and ultimately

the end-user as the key stakeholders.

Faculty of Engineering: As the governing body and overseer of the project, working closely with

the supervisor and teaching requires the core development team to consider particular constraints and

guidelines relating to the safety, privacy, codes, standards, manufacturability, ethics, and costs of the

project, with significant emphasis on the standards and codes. This stakeholder will require the development

team to adhere to certain protocols and standards when developing the core application, such as the

thoroughness of the project reports, clarifications on intentions, and consistent updates on the progress of

development. This was achieved as expectations were met and exceeded throughout the development

period, with all deadlines being met and project reports being successfully delivered. Moreover, as the

supplier of several physical parts required for the project to function, especially the IPS monitor, the design

team would have to consider budget restraints and the costs of acquiring the necessary technical

components. This guideline and stakeholder need to have the budget under a total sum of $400.00 was met

and exceeded, as the total costs were $222.78.

The Development Team, as another stakeholder, will require the elicitation of several stakeholder

needs and requirements, as these guidelines also contribute to shaping the development of the overall

project. As the main design engineers and integration team, several key design choices were made with the

considerations of development, such as the most effective way to implement a solution for the application.

This was executed and determined through the consideration of the following design criteria:

- Clear and effective design: By utilizing standard web design technologies such as HTML, CSS,

Node.JS, and Electron, this provides a flexible design with prebuilt standards for designing the user

interface, as opposed to creating and specifying items in a grid system similar to a Python or C++

graphical user interface (GUI) development design. This allows the team to scale back reasonably

on development and coding timeframes and allows the team to focus on testing and integration.

- Reasonably simple and standard development: Moreover, utilizing web design technologies in

conjunction with Electron allows for a simple translation from the constraints of a web page to a

fully standalone application. This was chosen as a simpler, familiar, and standardized alternative

to creating a barebones GUI utilizing other technologies, allowing for easier debugging as well as

compartmentalizing and mobilizing the simple application.

- Achievable functionality requirement was achieved by the integration team during the engineering

and development phase, which is critical in allowing the project to function up to the standards

outlined. With the integration of various widgets along with the Echo voice functionality, the

development team was able to achieve this stakeholder requirement through the rigorous

development process through various testing procedures as well as coding sprints.

Finally, the most important stakeholder is the end-user, which the guidelines and requirements will

influence the design of the project to a higher caliber. This user stakeholder process was conducted through

a user-centered design (UCD) iterative process. This is an optimistic approach that attempts to invent new

solutions from the perspective of human users and provides answers to individual needs. By understanding

the end-user and their requirements, the team is able to tailor specific design functionalities to achieve these

requirements, which involve requirement discovery, requirement classification, requirement prioritization,

and requirement specification, which is done through an iterative and agile process, which involves constant

feedback and improvement. By following the steps below, the team is able to identify and fulfill the end-

user stakeholder needs:

- Understanding the context of use: By creating specific use cases and using mockup demos, a

specific target environment is identified by the possible brainstorming issues a user may have

without the assistance or use of the product. This allows for certain constraints to be visualized and

illustrated from the perspective of the user, as the Magic Mirror can be applicable in certain

locations. This may cause constraints on the end-user, such as limited input functionality, use in a

wet environment, or the delayed or misjudged reaction of a user due to lighting, sleepiness, or time

of day. Ultimately by identifying the context of use, the team is able to identify slips or mistakes

of user error in handling and interacting with the product in a specific context.

- Specify user requirements through elicitation: Moreover, once the context has been identified and

understood, the user requirements are further clarified through elicitation, which will involve

conversing with the user or illustrating the required design implementations from the perspective

of a user. This put the development team as the end-user, with additional consultation from other

users in trial tests, such as housemates, classmates, or peers. This allowed the team to specify and

prioritize these formal requirements, such as the inability to interact physically with the Mirror, the

inability to use a mobile device in the washroom with occupied appendages, and the lack of

information available to the user when completing other unrelated tasks.

- Design solutions: Once these user requirements have been prioritized and specified, the team will

consider various solutions to implement, such as the inclusion of an internet of things (IoT) device,

Amazon Echo input with the user through natural language processing. By testing out various

designs for the user interface such as python GUI, or web development technologies, an effective

and clean design was achieved to relay information to the user in an optimal way. In addition, this

solution requires a functional back end stack that will load the relayed information to the user, while

integrating with the Amazon Echo module. Overall, this design was considered through the design

process, which is built upon the various user requirements that have been elicited from the previous

steps of UCD.

- Evaluate against requirement: This final step involves the feedback from potential end users,

alongside the supervisor and evaluator of the project that would place themselves from the end user

perspective. By receiving feedback on the functional measures implemented that address the user

requirements and guidelines, the team was able to narrow down the scope of identified issues, such

as PIR timeout, or voice accuracy of the input commands. This final step of the user centric design

principle is extremely effective in achieving the stakeholder needs of the end user, with direct

feedback on the features.

Finally, several other miscellaneousstakeholder needs have been considered with the overall design

of the product; however, these stakeholders are mostly out of scope and potentially irrelevant. Regardless,

the team still considers the possibility of future implementations that will include these, which are listed

below:

- Safety is considered in the overall design of the mirror. However, as a static application based on

software, physical safety is limited to the structural integrity of the physical mirror and ensuring it

has been properly mounted to avoid falling on to the end-user, which fails the user stakeholder

requirement of not being killed or physically maimed by the product.

- The privacy of the product is also considered, especially physical. As this IoT device concerns the

use of an internet-connected peripheral in a vulnerable context such as the washroom, the removal

of a camera or visual input is highly recommended and implemented in the final solution. This

prevents any software attacks from accessing visual data on unknowing users. By establishing this

privacy stakeholder, the product was able to exceed this requirement.

- Manufacturability is also considered alongside cost in the event of scaling to larger production. By

evaluating the overall cost and capabilities required to effectively produce a large quantity of the

product, the manufacturing methods and cost are accounted for to determine the margin of profit, as well as any special skills required. However, as the design is simple, no special tools or skills

are required.

- Lastly, ethics as a stakeholder is considered briefly, as we have not identified any ethical issues

with visualizing weather data in the washroom.

## Compliance with specifications

As stated in the blueprint, the project is mainly a software integration project. Therefore, the hardware

components are mediums in which our software operates on. No hardware will be created from scratch.

Instead, they will be utilized as a part of the smart mirror system.

The only hardware that was tested for the smart mirror system was the PIR sensor. We wanted to test

if the PIR sensor can detect movement within a 3m distance and if it can detect no movement for greater

than 30 seconds. Table 5 shows the results.

Table 5 Hardware specification of the PIR sensor

| Specification | Target Value | Tolerance | Achieved Value
1 | Detect movement within a 3m distance | 3m | 30cm | ~3m
2 | Detect no movement for greater than 30 seconds | 30 seconds | 10 seconds | ~32 seconds

Throughout the project, there have been many changes to the functional requirement. Some were

added because we did not initially anticipate having it until later stages, and one was added because it was

meant to be a stretch goal, but we managed to achieve it in our given timeframe.

Table 6 Software Specifications Table

1 | Functional requirements | Specification met?
1.1 | The mirror will be able to connect to OpenWeatherMap API service and display daily weather for Kingston, Ontario. | Yes
1.2 | The mirror will be able to connect to OpenWeatherMap API service location, such as city, province, and country | Yes
1.3 | The mirror will be able to accurately display current time and date (Eastern Standard Time) | Yes
1.4 | The mirror will be able to connect to Google Calendar’s API service, and users will be able to add/delete/update calendar events that will display dynamically on the mirror | Yes
1.5 | The mirror will be able to connect to Spotify’s API service, and users are able to pause/play/shuffle/choose songs through voice command. The display should be able to match said command. | Yes
1.6 | The mirror’s display will be activated only if the PIR sensor detects movement within 3m of its prereferral | Yes
1.7 | When no movement is detected for 30 seconds the mirror’s display will turn off | Yes
1.8 | The mirror will be able to navigate to different user pages through voice command and a given name | Yes

2 Interface requirements

| The interface from the device to the user: | Yes

| Display information using icons and text, using Raleway or Quicksand (font types). Other icons can be created in photoshop with a flat monochromatic design in white Respond to the user with information on: • Music • Weather • Time • Calendar
2.2 | The interface from the user to the device: Sync between the user device and display to show music, calendar, weather, time Request device with information on: • Music • Weather • Time • Calendar | Yes

3 Performance requirements

3.1 | Able to pull data from an API using HTTP get requests over Wi-Fi | Yes
3.2 | Updates the display portlets within a reasonable time (once per day) | Yes
3.3 | Updates the clock once per minute | Yes
3.4 | Recognizes and processes voice commands within the Amazon’s Alexa API specifications | Yes

## Conclusions and recommendations

### Further Research and Development

Currently, our project is in the proof of concept stage, with a lot of potential to expand further than the

current scope. Many improvements we wanted were previously stated as the stretch goals in the system

design section.

One of our improvement was to add RGB LED light strips surrounding the frame of the mirror. We

understand that it is very easy for people to lose track of time when showering or getting ready in the

morning. Therefore, by adding LED lights that progressively change color over time, we hope it can serve

as a visual cue indicator of how long the person has been in the washroom.

Another improvement would be to add more functions or APIs to the current pool. Right now, the user

is very limited in terms of what functions they have. More research and development for this project can

allow functions or services that users typically see on their smartphones, such as cellular services, video

playback, stocks, traffic reports, or email.

By providing some more of these features to the users, the mirror can be more suitable for a wider range

of audiences.

### Main Technical Lessons

The main technical lesson to be learned from this project is that software system integration is very

messy. And having knowledge and background is specific software domains is very useful to produce an

effective working product. For example, in our project, we used two environments the Amazon Skills Kit

developer tool and the Electron software framework (which is open source). Having communication

between these 2 separate platforms is an interesting challenge because any updates or changes from one of

the platforms can cause compatibility issues since Amazon and Electron operate as separate entities.

Therefore, reading documentation and understanding which versions are compatible with each other is crucial to a working system. However, as there is a growing market for voice-controlled smart home devices

and projects, software engineers of Amazon will continue to develop wrappers or frameworks that have

compatibility between different systems.

### Future Potential for the Project

From our research on the internet to the overwhelmingly positive feedback we got from students

during the capstone showcase, we believe that there is a market of people who would like to have a smart

mirror in their homes. The only problem is the product is not deemed as an essential good but more so a

luxury good to improve a person’s quality of life. A good comparison to a product like this would be

smartwatches.

However, with the increasing market of smart home assistants and IoT platforms, it is not unlikely

a smart mirror type system will reach the market in the distant future. An article from MarketLand estimates

that as of the 2nd quarter of 2019, there are approximately 76 million units of smart speakers are sold in the

U.S, with 70% of the market share dominated by Amazon alone. (Shown in Figure 15) [9] The objective

for these corporations is that they first need to integrate voice-assistant devices into people's lives, and once

that is integrated into, it is easier for them to push a product that can work with their smart home device.

Therefore, the potential for a product like this is very strong.


Figure 15 U.S smart speaker market share (millions)

### Pricing

Overall, with the correct cost analysis, business model, and go to market strategy, this project would

have a potential in the market as a commercialized product for general consumer use. However, this will

consider several key factors first, such as manufacturing constraints and costs. As the construction of the

solution implemented consists of a basic frame utilizing a one-way mirror over an LCD monitor, this

product does not require any proprietary or specialized manufacturing methods, which in turn will lower

manufacturing tooling and training costs. This lean development principle applied throughout the product

keeps the product lightweight and modular, which is a significant market advantage. As outlined in table 2,

the overall estimated cost will amount to $222.78 CAD, with the main components listed as Raspberry PI,

LCD Screen, and one-way mirror, which are easily manufactured and sourced from various suppliers.

However, considering usual consumer-friendly prices while also factoring a minor percentage of revenue

towards research and development, a suggested retail price of $299.99 CAD would be suggested. However,

without additional factors considered, such as marketing, deployment, various scale points, and other

business costs, an estimated cost for a manufactured version can vary.

## Group Effort table

Table 7 Group Effort Table

Name | Overall effort expended (%)
Adams | 100
Ian | 100
Kingsley | 100

## Appendix - Survey Results






## References

[1] From Machine-to-Machine to the Internet of Things: Introduction to a New Age of Intelligence,” ProtoView, vol. 1, no. 44. Ringgold Inc, Beaverton, 12-Nov-2014.
[2] M. Chen, J. Wan, and F. Li, “Machine-to-machine communications: architectures, standards and applications.(Report),” KSII Transactions on Internet and Information Systems, vol. 6, no. 2, pp. 480–497, Feb. 2012.
[3] “IDC Forecasts Worldwide Spending on the Internet of Things to Reach $745 Billion in 2019, Led by the Manufacturing, Consumer, Transportation, and Utilities Sectors,” IDC. [Online]. Available: https://www.idc.com/getdoc.jsp?containerId=prUS44596319. [Accessed: 06-Apr-2020].
[4] Hiroko Sukeda, Youichi Horry, Yukinobu Maruyama, and Takeshi Hoshino, “Information-accessing furniture to make our everyday lives more comfortable,” IEEE Transactions on Consumer Electronics, vol. 52, no. 1, pp. 173–178, Feb. 2006.
[5] Dave Leggett, “JAPAN: Nissan develops ‘smart rearview mirror,’” Feb. 2014.
[6] K. Jin, X. Deng, Z. Huang, and S. Chen, “Design of the Smart Mirror Based on Raspberry PI,” in 2018 2nd IEEE Advanced Information Management,Communicates,Electronic and Automation Control Conference (IMCEC), 2018, pp. 1919–1923.
[7] D. Besserer, J. Bäurle, A. Nikic, F. Honold, F. Schüssel, and M. Weber, “Fitmirror: a smart mirror for positive affect in everyday user morning routines,” in Proceedings of the Workshop on multimodal analyses enabling artificial agents in human-machine interaction, 2016, pp. 48–55.
[8] D. Gold, D. Sollinger, and Indratmo, “SmartReflect: A modular smart mirror application platform,” in 2016 IEEE 7th Annual Information Technology, Electronics and Mobile Communication Conference (IEMCON), 2016, pp. 1–7.
[9] G. Sterling, "Alexa devices maintain 70% market share in U.S. according to survey," Marketing Land, 09 08 2019. [Online]. Available: https://marketingland.com/alexa-devices-maintain-70-market-share-in-u-s-according-to-survey-265180. (https://marketingland.com/alexa-devices-maintain-70-market-share-in-u-s-according-to-survey-265180) [Accessed 04 05 2020].

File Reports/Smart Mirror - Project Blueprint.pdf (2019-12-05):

## ELEC 490/498 Project Blueprint

Project title: Smart Mirror

Group #: 36 Group members: Ian Chang, Kingsley Chu, Adams Liu

### 1. Design problem

The Canadian Internet Registration Authority (CIRA) reports that in 2019, 73% of Canadians spend an average of 3-4 hours online per day and 1/5 of Canadians cannot stay away from regular internet usage for more than 8 hours [1]. Canadians see a growing need to remain connected with their online data and to integrate it with their daily life. CIRA, in the same 2019 study, has also found that 46% of all Canadians use their mobile phones while using the washroom [1]. While Canadians want to remain connected with their online media platforms, the washroom setting may act as a barrier. Using a digital device in a washroom creates risk for water damage which can become a safety hazard. Therefore, a device is needed to allow users to have access to relevant information in a washroom setting through a hands-free experience.

### 2. System specifications

The Smart Mirror project is mainly a software integration project. Therefore, the hardware components are mediums in which our software operates on. No hardware will be created from scratch, instead, they will be utilized as part of smart mirror system. The hardware involved includes a Raspberry Pi 3 Model B, Google AIY Voice Kit, and a 21” LCD
monitor. Listed below are the hardware specifications of interest for the respected hardware.
Raspberry Pi 3 Model B | Google AIY Voice Kit | Acer SB220Q bi 21.5" Full HD
1.2GHz Quad-Core ARM Cortex-A53 | 1.6" speaker | 21.5" Full HD (1920 x 1080) Widescreen IPS Display
802.11 bgn Wireless LAN and Bluetooth 4.1 (Bluetooth Classic and LE) | | Refresh Rate: 75Hz - Using HDMI Port. 4ms Response time
1GB RAM | | Processor Count: 1
64 Bit CPU | | HDMI port
4 x USB ports
Full size HDMI port
Micro SD port for loading your operating system and storing data

1 Functional requirements
1.1 | Weather display which includes: a high and low temperature, average temperature, icon to determine condition, weekly forecast, pull data from openweathermap API
1.2 | Location data display which includes city, province, and country
1.3 | Time display which displays the current time in time zone located by openweathermap.API and includes the current date
1.4 | Quote of the day (or static encouraging phrases) displayed on the screen such as: • You miss a 100% of the shots you don’t take – Wayne Gretzky • Hey, sexy!

2 Interface requirements
2.1 | Interface from device to user • Display information using icons and text, using Raleway or Quicksand. Other icons can be created in photoshop with a flat monochromatic design in white • Respond to the user with information on: • Music • Weather • Time • Calendar
2.2 | Interface from user to device • Sync between user device and display to display calendar, weather, time • Request device with information on: • Music • Weather • Time • Calendar

3 Performance requirements
3.1 | Able to pull data from an API using HTTP get requests over Wi-Fi
3.2 | Updates the display portlets within a reasonable time (once per day)
3.3 | Updates the clock once per minute
3.4 | Recognizes and processes voice commands within the Amazon’s Alexa API specifications

### 3. Methodology

### 3.1 Approach

The design approach that the team decided to go with a voice-controlled smart mirror. The smart mirror is a reflective surface that also displays relevant information to the user. It consists of a one-way reflective film that covers over an LCD monitor. The userinterface will be custom-designed, powered by a Raspberry Pi. A Google AIY voice
kit module will be used on the Raspberry Pi to integrate Amazon Alexa API voice control features into the smart mirror’s software capabilities. The smart mirror itself will be constructed using wooden panels which would act as the frame around the one-way film. An LCD screen would be used placed behind the one-way film, where the relevant applications will be displayed against the film diffusing over to the other side. The device’s software system will feature a Linux OS powered by a Raspberry Pi unit. A PIR sensor will also be equipped on the device to detect the user’s presence, allowing the device to power on or off automatically, lower overall inefficiencies to power usage.

### 3.2 Design tools, hardware, instrumentation

For the smart mirror project, the main hardware parts that will be used include the Raspberry Pi 3 Model B (RP3), Google AIY Voice Kit, and a 21” LCD monitor. The Raspbian OS will be running on the Raspberry Pi and the user settings app will be able to run on any Android device/android simulator.

Hardware instrumentations for this project include: HDMI cable, USB flash drive, conducting wires, micro SD memory card (32GB), wire cutters, multimeter, power adapters, RGB LEDs (optional), PIR sensor (optional), wooden frame, wood glue, hammer, saw, nails/screws, screwdriver, ruler, metal brackets, sandpaper, wood paint, paintbrush. The HDMI cable is used to connect the RP3 to the LCD monitor. The RP3 will also be connected to conducting wires and designed to support a PIR sensor for motion detection and RGB LEDs for visual indication. The entire smart mirror system will be held together by a woodworking frame that will be designed and built from scratch.

The hardware platform used for the project will be Raspberry Pi 3, running the default OS Raspbian. The default OS will be modified the GUI to display data using a combination of HTML, CSS, and JavaScript to create an interactive interface. The design of the wooden frame can be constructed and mocked with the use of a photo editing software to sketch out the dimension and physical specifications such as Adobe Photoshop, Pixlr free online editor, Solid Edge, as potential CAD software.

### 3.3 Validation

There are three distinct phases of testing for this project: software, hardware, and integration testing. The software and hardware of the mirror will be tested individually for proper functionality, which will then be followed by tests for integration between the two systems. For the software testing phase, rigorous stress testing will be done on the software applications to ensure that basic functionalities of the application are met. Various inputs, both valid and invalid, would be entered to attempt find mistakes or to crash the application. If the application crashes, the application integration code will be reviewed to check for potential bugs. An example of stress testing would include inputting various preference on the weather application and checking that the correct location, temperature, and time are displayed. In addition to checking functionality, the tests performed on the application can be also be used to diagnose the device’s internet connectivity and application’s visual fidelity on the LCD display. After the bugs in the application are identified and fixed, the testing process is repeated until no additional issues are found in later iterations. For the hardware phase of testing, the physical components used in the device such as the Raspberry Pi, Google AIY voice kit and the LCD display will be thoroughly tested for proper functionality. Proper testing of the physical components will ensure that the system integration between software and hardware will proceed more smoothly. Examples of functionality tests would include testing for accuracy and responsiveness of voice recognition on the AIY voice kit. The structural integrity of the mirror frame will also be tested to make sure that assembly of all the components will fit properly and that the device will have acceptable durability. The final integration testing stage will check for any issues in the compatibility between the software and hardware systems. Various tests will be done to check for the acquisition of data from hardware to software, such as correct outputs from software to hardware, normal/abnormal data entry, and in addition to overall system timing/performance.

### 4. Milestones

No. | Milestone | Due date | Responsible member(s)
1 | • Research and Development: Have a detailed understanding of the entire network and finalize system design. (i.e. know how each component will be communicating with each other via which software platform). | Week 3 | Ian, Adams, Kingsley
2 | • Have a list of Bill of Materials submitted (not including wooden frame). • Will be able to run and display all preliminary API software on RP3. | Week 5 | Adams Kingsley
3 | • Have the Amazon Alexa API integrated into the system and allow apps to launch base on voice commands. | Week 8 | Adams
4 | • A well-designed display interface when running smart mirror system. | Week 11 | Kingsley
5 | • Create a server/database where it keeps track of registered users and preferred software API’s that are used. Have a way to track other data (i.e. Time of use, duration). | Week 13 | Ian
6 | • Continuous testing and development of the integrated system to ensure all validation test cases are completed. • Blueprints and outline of the wooden frame are created. Bill of Materials sent for wooden construction. | Week 16 | Adams, Kingsley Ian
7 | • Wooden Frame Construction. • Integrated PIR Sensor or RGB LEDs (optional). | Week 19 | Ian, Kingsley Adams
8 | Final deliverable. | Week 23 | All members
9 | Final project report, presentation. | Week 24 | All members

### 5. Budget

### 5.1 Materials and Supplies

Item | Price | Reference
1x3x6 Pine Lumber x2 | $5.95 x 2 = $11.90 | [2]
21’ Monitor | $118.48 | [3]
Window Film | $47.21 | [4]
PIR Sensor | $5.99 | [5]
RGB Programmable LEDs | $15.99 | [6]
Google AIY Voice Kit | $27.77 | [7]
32 Gb SD Card
Subtotal | $227.34
HST | $29.55
Total | $256.89

The budget table above includes all the materials that the team needs and has yet to purchase for the project. The items in the table without a price listed next to it are items that the team members already own and plan to use for the project.

### 5.2 Contributions from other sources

Currently, the team has no plans to utilize resources that go beyond the ECE department’s support, and no plans on collaborating with other companies.

### 6. References

[1] Canadian Internet Registration Authority, "Canada's Internet Factbook 2019," Canadian Internet Registration Authority, March 2019. [Online]. [Accessed 18 September 2019].
[2] Home Depot, "THD 1x3x6 Select Pine," Home Depot, [Online]. Available: https://www.homedepot.ca/product/thd-1x3x6-select-pine/1000115573 . [Accessed 19 September 2019].
[3] Amazon, "Acer SB220Q bi 21.5" Full HD (1920 x 1080) IPS Ultra-Thin Zero Frame Monitor (HDMI & VGA Port)," [Online]. Available: https://www.amazon.ca/Acer-SB220Q-Ultra-Thin-Frame-Monitor/dp/B07CVL2D2S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. [Accessed 19 September 2019].
[4] Amazon, "Gila Window Films PRS361 Privacy Residential Window Film, Mirror, 36-Inch by 15-Feet," Amazon, [Online]. Available: https://www.amazon.ca/Gila-LES361-Control-Residential-Platinum/dp/B000H5XTKG/ref=pd_bxgy_60_img_3?. [Accessed 19 September 2019].
[5] Amazon, "Aukru HC-SR501 Human Body Pyroelectricity Infrared PIR Motion Detector Sensor Module for Arduino, Raspberry Pi and Microcontrollers Electronic Projects," Amazon, [Online]. Available: https://www.amazon.ca/Aukru-Pyroelectricity-Raspberry-Microcontrollers-Electronic/dp/B019SX734A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.. [Accessed 19 September 2019].
[6] Amazon, "ALITOVE 3.2ft 1M 60 Pixels Programmable Individual Addressable LED Strip Light WS2812B WS2811 Built-in 5050 RGB LED Strip DC5V Black PCB Non-waterproof IP33," Amazon, [Online]. Available: https://www.amazon.ca/ALITOVE-Programmable-Individual-Addressable-Non-waterproof/dp/B01MG49QKD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.. [Accessed 19 September 2019].
[7] Amazon, "Google AIY Voice Kit," Amazon. [Online]. [Accessed 19 September 2019].

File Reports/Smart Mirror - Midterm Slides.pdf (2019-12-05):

# Smart Mirror

MIDTERM PROGRESS
GROUP 36: KINGSLEY CHU, ADAMS LIU, IAN CHANG

DATE: DEC/05/2019

# Divided the roles into 3 parts


Amazon Voice Development
[Adams Liu]


Fullstack + GUI Development [Kingsley Chu]


Hardware/Frame Development [Ian Chang]

# Hardware & Materials


# List of Materials

Item | Price
1x3x8 Pine Lumber | $8.21
1x2x8 Pine Lumber | $5.80
21’ Monitor (19.6 x 8.3 x 15.11) | $132.82
Window Film (36” by 15ft) | $50.69
PIR Sensor | $3.44
RGB Programmable LEDs | $13.99
Plexiglass (12x24”) | $27.49
Subtotal | $242.44
HST | $35.61
Total | $278.05

# Alexa voice integration


# Voice User Interface


# Utterance and Intent (Schedule)

- Utterance:
- "what's my schedule"?
- "what does my schedule look like for today?"
- "what's today's agenda?"
- "what's today's to-do list?"
- "what am I doing today?"
- Intent 1: ReadScheduleIntent {value: 2019-12-05}
- Call onto calendar API and return and responds by listing out schedule items for listed date
- Intent 2: OpenCalendarIntent{value: 2019-12-05}
- Communicates with Raspberry Pi to launch Calendar display for listed date

# Software & UI


9:59

Wednesday, March 16

23

°

## Clear Sky

Toronto
Hello,

# John!

a.m.


# Next Steps

# Build the mirror

# Integration development between Alexa, Raspberry Pi, and Mirror

# Integration testing with between the ecosystem

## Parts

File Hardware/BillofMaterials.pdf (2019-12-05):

### Group 36, Smart Mirror Supply List

Item | Price | Links
1x3x8 Pine Lumber | $8.21 | [1]
1x2x8 Pine Lumber | $5.80 | [2]
21’ Monitor (19.6 x 8.3 x 15.11) | $132.82 | [3]
Window Film (36” by 15ft) | $50.69 | [4]
PIR Sensor | $3.44 | [5]
RGB Programmable LEDs | $13.99 | [6]
Plexiglass (12x24”) | $27.49 | [7]
Subtotal | $242.44
HST | $35.61
Total | $278.05

### Links

[1] https://www.homedepot.ca/product/thd-1x3x8-select-pine/1000115576
[2] https://www.homedepot.ca/product/thd-1x2x8-select-pine/1000115500
[3] https://www.amazon.ca/Acer-SB220Q-Ultra-Thin-Frame-Monitor/dp/B07CVL2D2S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. (https://www.amazon.ca/Acer-SB220Q-Ultra-Thin-Frame-Monitor/dp/B07CVL2D2S?s=electronics)
[4] https://www.amazon.ca/Gila-LES361-Control-Residential-Platinum/dp/B000H5XTKG/ref=pd_bxgy_60_img_3? (https://www.amazon.ca/Gila-LES361-Control-Residential-Platinum/dp/B000H5XTKG/ref=pd_bxgy_60_img_3?)
[5] https://www.amazon.ca/dp/B075CNDXTB/ref=dp_cerb_1
[6] https://www.amazon.ca/dp/B01LSF4QDM/ref=dp_cerb_1
[7] https://www.amazon.ca/Acrylic-Plexiglass-SimbaLux-Transparent-Projects/dp/B07D54TVYH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 (https://www.amazon.ca/Acrylic-Plexiglass-SimbaLux-Transparent-Projects/dp/B07D54TVYH?s=kitchen)

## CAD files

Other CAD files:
Hardware/shadowframe.skp

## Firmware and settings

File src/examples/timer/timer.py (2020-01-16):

#
# Copyright 2019 Amazon.com, Inc. or its affiliates.  All Rights Reserved.
# These materials are licensed under the Amazon Software License in connection with the Alexa Gadgets Program.
# The Agreement is available at https://aws.amazon.com/asl/.
# See the Agreement for the specific terms and conditions of the Agreement.
# Capitalized terms not defined in this file have the meanings given to them in the Agreement.
#

import logging
import sys
import threading
import time

from gpiozero import AngularServo
import dateutil.parser

from agt import AlexaGadget

logging.basicConfig(stream=sys.stdout, level=logging.INFO)
logger = logging.getLogger(__name__)

GPIO_PIN = 25

SERVO = AngularServo(GPIO_PIN, initial_angle=90, min_pulse_width=0.0005, max_pulse_width=0.002)

class TimerGadget(AlexaGadget):
    """
    An Alexa Gadget that reacts to a single timer set on an Echo device.

    A servo rotates a disc to indicate the remaining duration of the timer,
    when the timer expires, and when a timer is canceled.

    Threading is used to prevent blocking the main thread when the timer is
    counting down.
    """

    def __init__(self):
        super().__init__()
        self.timer_thread = None
        self.timer_token = None
        self.timer_end_time = None

    def on_alerts_setalert(self, directive):
        """
        Handles Alerts.SetAlert directive sent from Echo Device
        """
        # check that this is a timer. if it is something else (alarm, reminder), just ignore
        if directive.payload.type != 'TIMER':
            logger.info("Received SetAlert directive but type != TIMER. Ignorning")
            return

        # parse the scheduledTime in the directive. if is already expired, ignore
        t = dateutil.parser.parse(directive.payload.scheduledTime).timestamp()
        if t <= 0:
            logger.info("Received SetAlert directive but scheduledTime has already passed. Ignoring")
            return

        # check if this is an update to an alrady running timer (e.g. users asks alexa to add 30s)
        # if it is, just adjust the end time
        if self.timer_token == directive.payload.token:
            logger.info("Received SetAlert directive to update to currently running timer. Adjusting")
            self.timer_end_time = t
            return

        # check if another timer is already running. if it is, just ignore this one
        if self.timer_thread is not None and self.timer_thread.isAlive():
            logger.info("Received SetAlert directive but another timer is already running. Ignoring")
            return

        # start a thread to rotate the servo
        logger.info("Received SetAlert directive. Starting a timer. " + str(int(t - time.time())) + " seconds left..")
        self.timer_end_time = t
        self.timer_token = directive.payload.token

        # run timer in it's own thread to prevent blocking future directives during count down
        self.timer_thread = threading.Thread(target=self._run_timer)
        self.timer_thread.start()

    def on_alerts_deletealert(self, directive):
        """
        Handles Alerts.DeleteAlert directive sent from Echo Device
        """
        # check if this is for the currently running timer. if not, just ignore
        if self.timer_token != directive.payload.token:
            logger.info("Received DeleteAlert directive but not for the currently active timer. Ignoring")
            return

        # delete the timer, and stop the currently running timer thread
        logger.info("Received DeleteAlert directive. Cancelling the timer")
        self.timer_token = None

    def _run_timer(self):
        """
        Runs a timer
        """
        # check every 200ms if we should rotate the servo
        cur_angle = 180
        start_time = time.time()
        time_remaining = self.timer_end_time - start_time
        self._set_servo_to_angle(cur_angle, timeout=1)
        while self.timer_token and time_remaining > 0:
            time_total = self.timer_end_time - start_time
            time_remaining = max(0, self.timer_end_time - time.time())
            next_angle = int(180 * time_remaining / time_total)
            if cur_angle != next_angle:
                self._set_servo_to_angle(cur_angle, timeout=0.3)
                cur_angle = next_angle
            time.sleep(0.2)

        # the timer is expired now, rotate servo back and forth
        # until timer is cancelled
        while self.timer_token:
            self._set_servo_to_angle(175, timeout=1)
            self._set_servo_to_angle(5, timeout=1)

        # the timer was cancelled, reset the servo back to initial state
        self._set_servo_to_angle(0, timeout=1)

    def _set_servo_to_angle(self, angle_in_degrees, timeout):
        """
        Sets the servo to the specified angle. Keep this between 0 and 180
        """
        # set the angle of the Servo (min = -90, max = 90)
        SERVO.angle = 90 - float(angle_in_degrees)
        logger.debug('Setting servo to: ' + str(angle_in_degrees))
        time.sleep(timeout)
        SERVO.detach()


if __name__ == '__main__':
    try:
        TimerGadget().main()
    finally:
        logger.debug('Cleaning up GPIO')
        SERVO.close()
